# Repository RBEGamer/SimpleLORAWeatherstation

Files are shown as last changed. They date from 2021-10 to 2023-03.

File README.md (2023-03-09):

# SimpleLORAWeatherstation

Simple temperature and rel. humidity Lora-Wan sensor based on the DHT22 and RFM95/RFM96 in interaction with an Arduino Nano.

The special feature of this version is the use of the Lora radio standard in combination with the Lora-Wan protocol. 
This allows the reception of sensor data over many kilometers.
To enable the transmission of the sensor data to the Internet, a decentralized network of receiving stations (gateways) is used.
These are usually provided by private individuals or companies.

Another advantage of this architecture is that not everyone needs a gateway who wants to send data with his Lora-Wan device.
Of course, only as long as a gateway is in range. For this purpose, there are ready-made maps that show the coverage at a location.

These gateways can send their data to a server on the Internet, which then provides them as e.g. REST api.
In this case we use the TTN provider [The Things Network (TTN)](https://www.thethingsnetwork.org).

## EXAMPLE SENSOR

### FINAL SENSOR

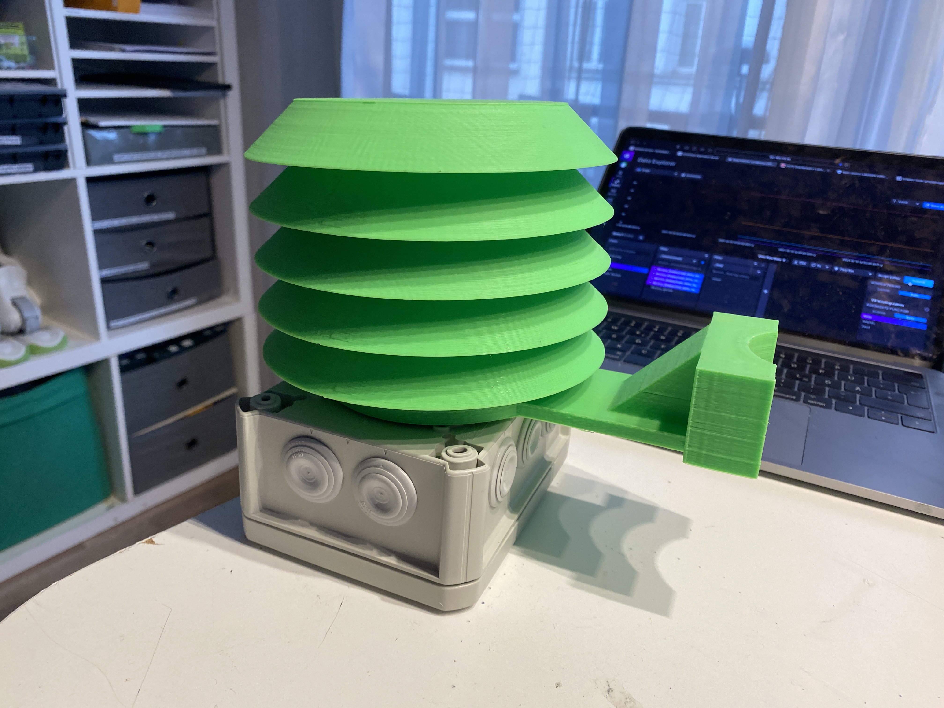
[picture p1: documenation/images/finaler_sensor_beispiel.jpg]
FINALER_SENSOR


### WITH MOUNTED SOLAR PANEL

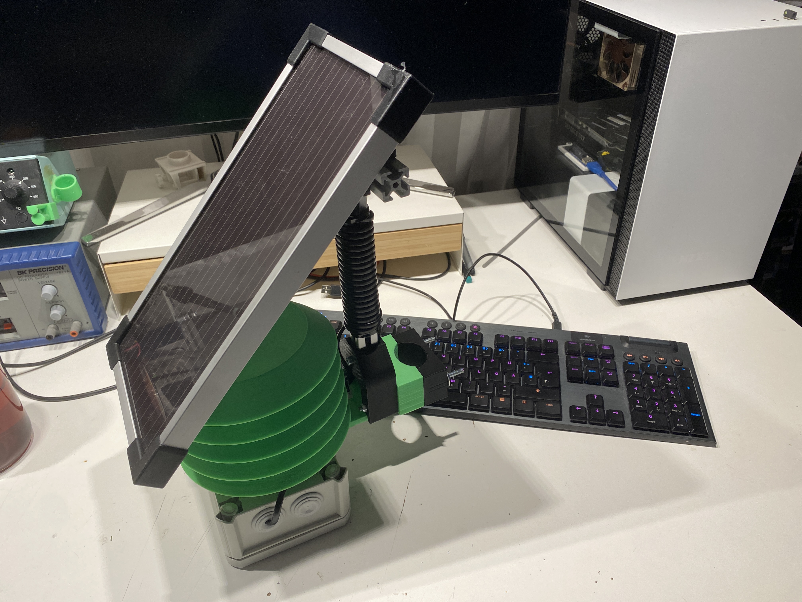
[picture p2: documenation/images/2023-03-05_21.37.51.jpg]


### PROTOTYPE

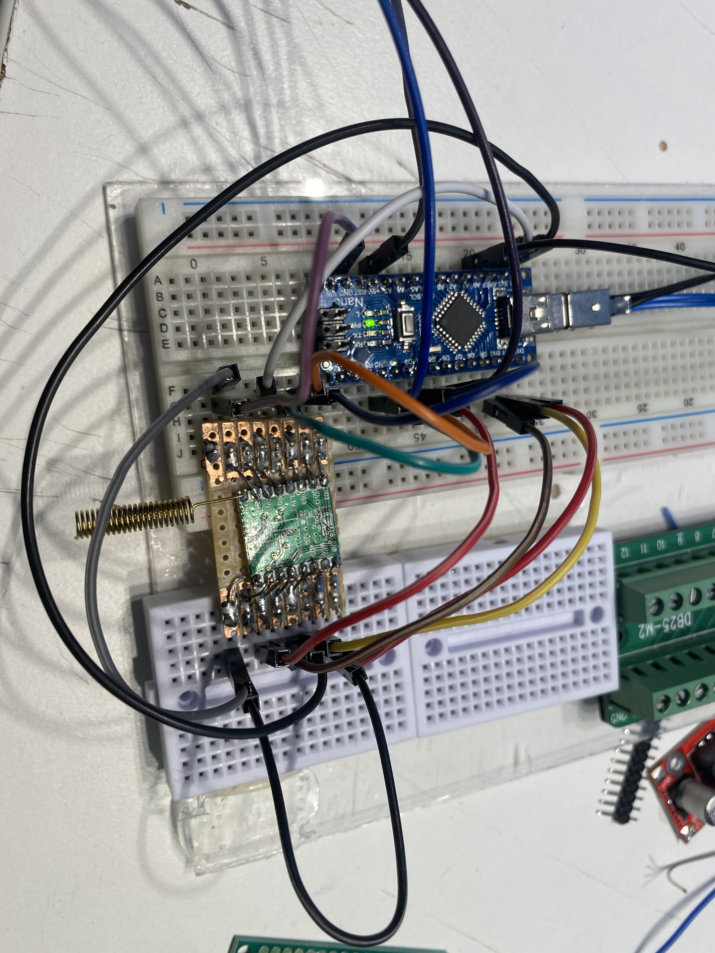
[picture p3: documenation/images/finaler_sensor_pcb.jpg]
PCB


## SETUP

### HARDWARE SETUP

#### COMPONENTS

* Arduino Nano
* DHT22
* RFM95, RFM95W, RFM96
* Steckbrett
* Jumperwires

* 3D printed parts - `src/src_stl`
* IP54 case 150x110x70mm

* `Adafruit Universal USB DC Solar Lithium Ion Polymer Lipo Charger` - Solar Support
* `10W Solarpanel 12V ` - Solar Support
* `iPo Akku Lithium-Ion Polymer Batterie 3,7V 2000mAh` - Solar Support

#### TOOLS

* soldering iron

#### SCHEMATIC

The construction of the circuit is relatively simple. However, the `RFM95` module cannot be plugged directly onto the breadboard, because this uses a different grid size of 2.0mm and the breadboard 2.54mm. So solder jumperwires directly or use a custom PCB - `src/src_rfmbreadboardadapter`.

The Arduino Nano and the RFM95 module communicate with each other via the SPI bus. In addition, the RFM95 module uses four other GPIO pins of the Arduino to exchange further status information with them. This includes a `RESET` signal and a receive event signal.

The SPI bus consists of the following signals in this configuration:

* `SCK` - Clock
* `MOSI` - Master Out Slave In 
* `MISO` - Master In Slave Out
* `CS` - Chip Select
* 
This way the RFM95 module is connected to the Arduino Nano as follows:

| Arduino Nano  	| RFM95 	|
|---	|---	|
| GND 	| GND 	|
| 3V3 	| 3.3V / VCC 	|
| D13 	| SCK 	|
| D12 	| MISO 	|
| D11 	| MOSI 	|
| D10 	| NSS 	|
| D5 	| RST 	|
| D2 	| DIO0 	|
| D3 	| DIO1 	|
| D4 	| DIO4 	|

After the RFM module has been connected, the DHT22 sensor can be connected.
However, this is only an example and other sensors can be used later.
It uses a bus protocol for communication which sends the sensor data to the Arduino via a GPIO.
So only one pin is used at the Arduino.
The bus is operated in a pull-up configuration, so an additional 10k resistor must be connected against 3.3V and the data pin.
Thus the 10K resistor is installed between DHT pin 1 and DHT pin 2.

| Arduino Nano 	| DHT22 	|
|---	|---	|
| GND 	| Pin 4 (GND)  	|
| 3V3 	| Pin 1 (VCC)  	|
| D6 	| Pin 2 (Data) 	|

The following graphic shows an exemplary circuit design.

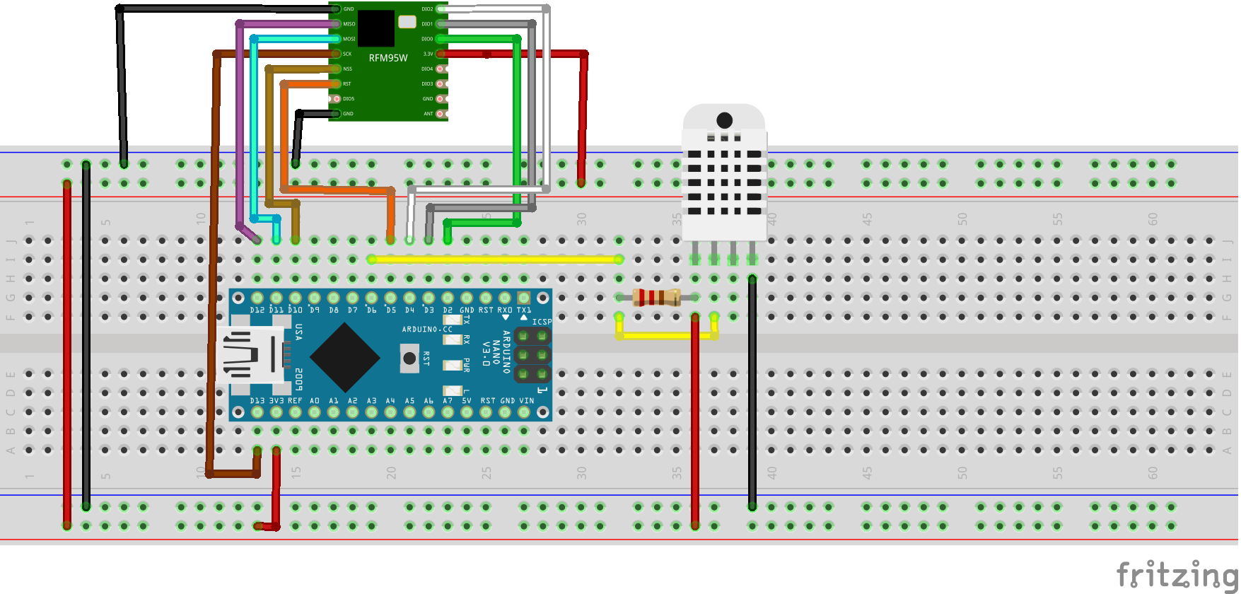
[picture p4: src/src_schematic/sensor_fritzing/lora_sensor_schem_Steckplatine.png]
STECKBRETT_SCHALTUNG


### The Things Network

In order to be able to program our sensor later on, it must first be christened. Each Lora-Wan device gets a fixed ID from the network to be used. In this case it is the TTN and there the sensor has to be registered. After this we get two keys, which are needed for an encrypted connection between. These are then inserted into the later Arduino program.

### Application registration

After registering an account, the TTN offers two options in the TTN Console:

* Application
* Gateway

The TTN groups multiple Lora devices into Applications, so a new Application with any name must be created first.

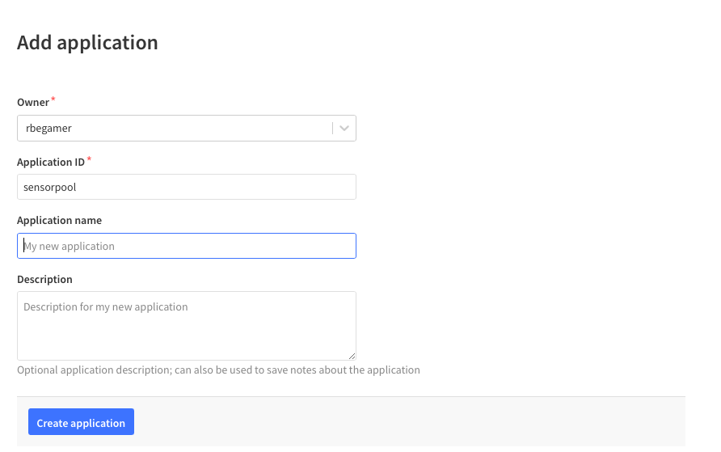
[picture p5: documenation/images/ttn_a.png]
Register Application


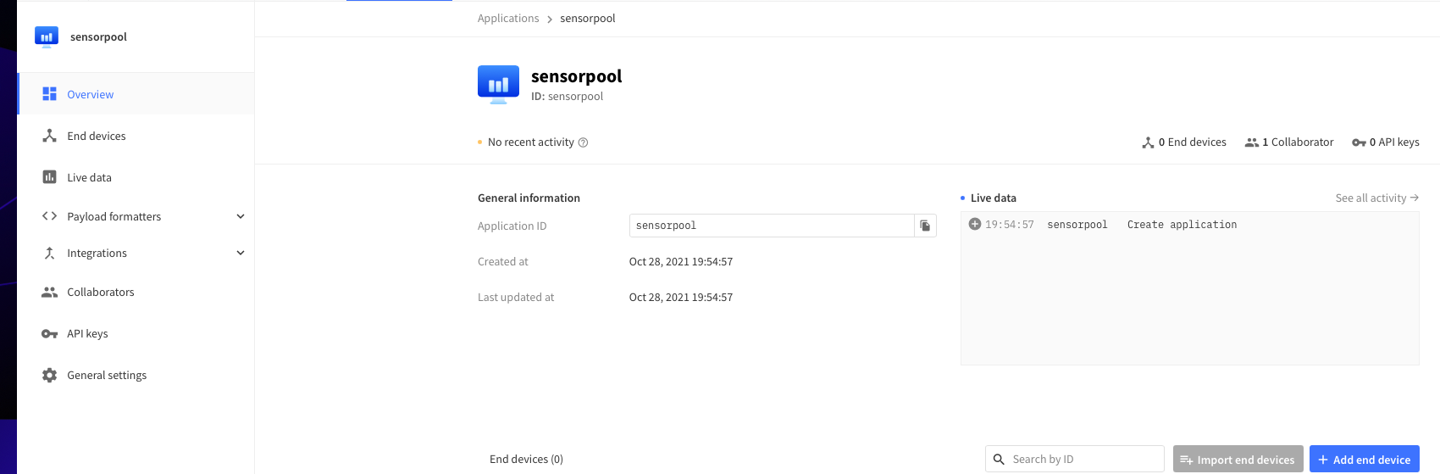
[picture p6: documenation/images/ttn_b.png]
Application


After creation, a Lora Wan device can be added via the **+ Add Enddevice** button.
Some information must be specified here. Since this is a self-built sensor, there is no ready template for it that can be used.

Here you must switch to the "Manually" tab and enter the following data:

| Key 	| Value 	|
|---	|---	 |
| Frequency plan	 | Europe 863-870MHz SF9 for RX2 - recommended |
| LoRaWAN Version 	 | MAC V1.0.3 |
| Activation mode 	 | Activation by personalisation (ABP) |

Then click on the three "Generate" buttons and finally "Register Device".
This completes the registration of the sensor.

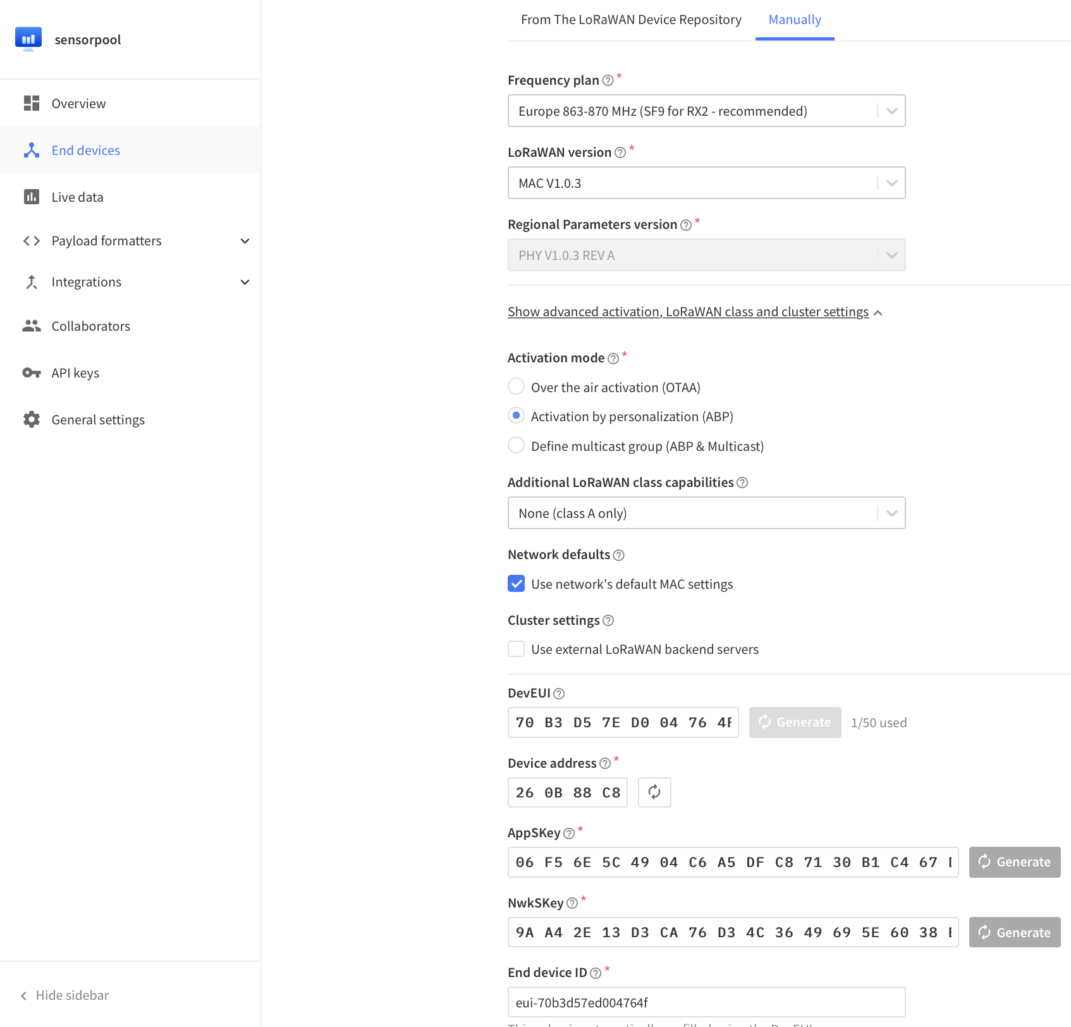
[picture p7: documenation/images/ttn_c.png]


On the overview, there is now some information. Here, three details about the parameterization are important.
These can be displayed in different formats. Click on the eye to display the key and the "<>" button to change the display.
The required information is listed in the following table.

| Information | Darstellung | Beispiel |
|---	|--- |--- |
| Device Adress	 | HEX, MSB ohne 0x | 260BA509 |
| NwkSKey | HEX, MSB | 0xE4, 0x14, 0xC5, 0x65 |
| AppSKeys | HEX, MSB | 0x0D, 0x79, 0xB8, 0x87.  |

The last step is only important here during development.
The network and the sensor remember how many packets they have already exchanged.
If the sensor is reprogrammed, this counter is not stored in the EEProm, they differ and the network no longer accepts packets from the sensor. Therefore this check is switched off for test purposes.

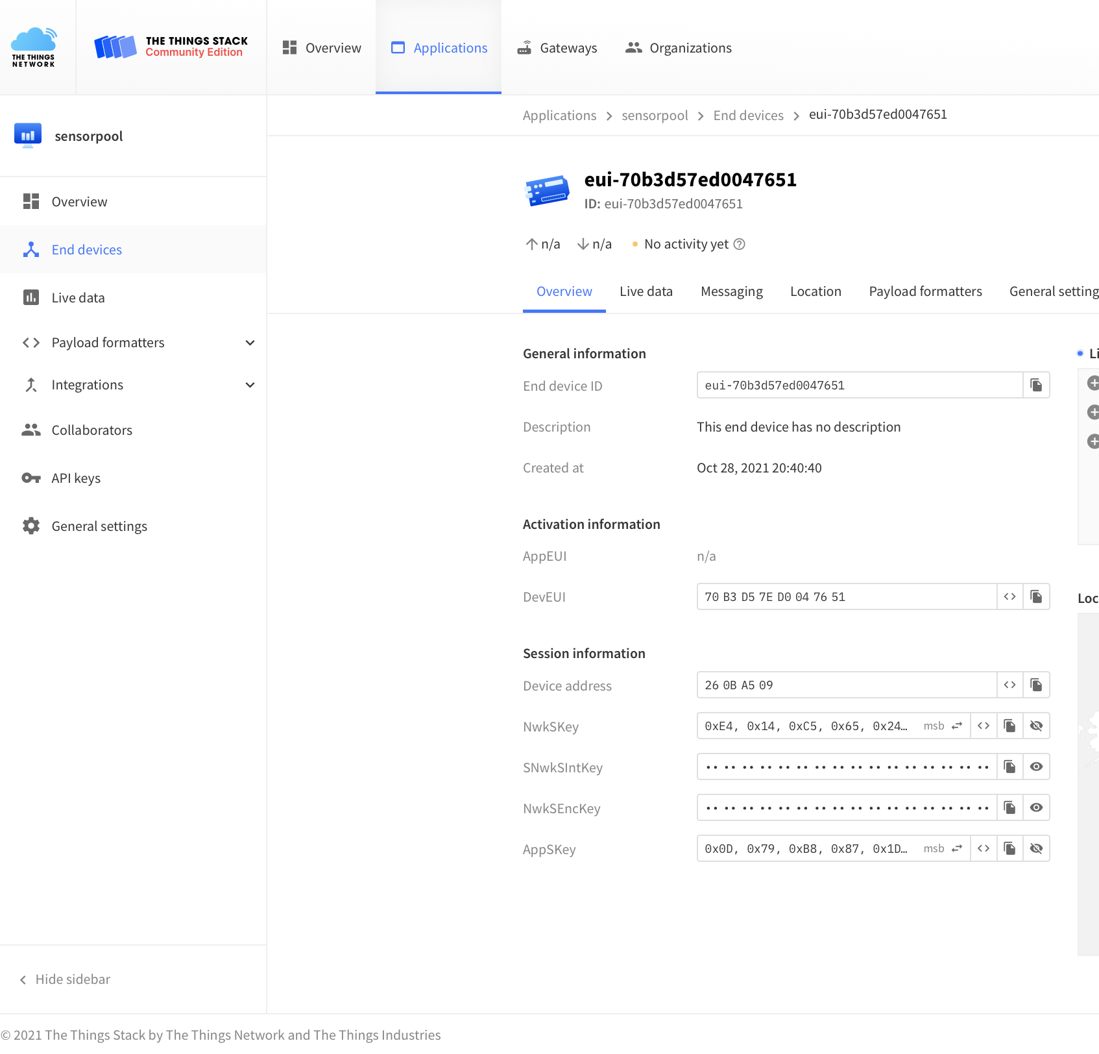
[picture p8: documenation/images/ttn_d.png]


Dazu auf der Sensor-Seite unter `General Settings -> Network Layer -> Advanced MAC settings -> Resets FRame Counter` auf `Enabled` setzten.

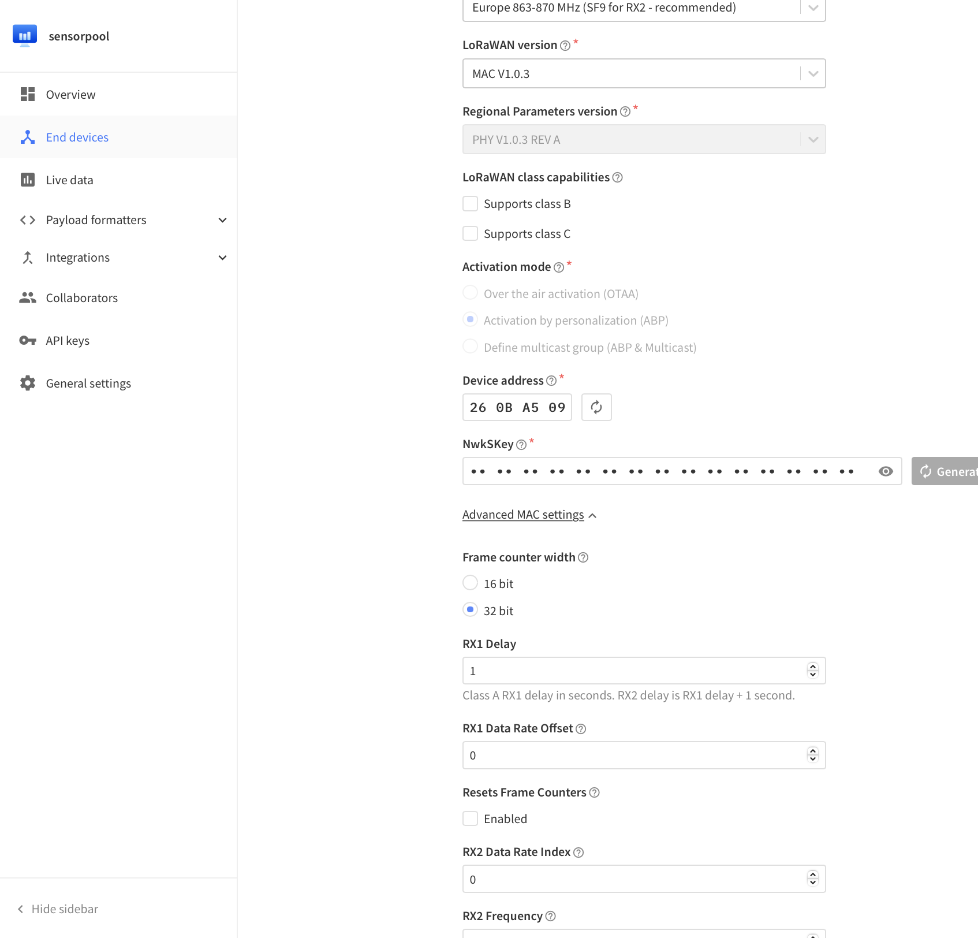
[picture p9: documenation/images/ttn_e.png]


### SOFTWARE SETUP ARDUINO

The Arduino Nano is programmed with the Aruino IDE. For the components used, however, ready-made libraries must be installed, which enable the simple control of the RFM95 module, as well as the DHT22.

Also the LoraWan protocol which is used here already exists in a corresponding library.

This can be done by the Arduino-Library Manager or by copying the corresponding folders from the `src_arduino/required_libraries` directory into the `Documents/Arduino/library` folder of the PC.

The following libraries must thus be installed:

| Arduino Libaray Name.  	|
|-------------------------	|
| Adafruit_Unified_Sensor 	|
| DHT_sensor_library      	|
| IBM_LMIC_framework      	|

All other software components are already included in the Arduino IDE installation, e.g. for the SPI communication.

After installing the libraries, the source code for the sensor can be opened.

This is located in the folder `src_arduino/lora_dht22_apb/lora_dht22_apb.ino`.
Here the necessary settings for the above pinouts have already been set.

Finally, the sensor must be parameterized and coupled with the one created in the TTN network.
For this purpose three different keys were created during the registration of the sensor in the TTN.

These must now be entered in the program as follows:

```c++
41 | //-------------------- LORA CONFIG ----------------------- //
42 | // NwkSKey MSB
43 | static const PROGMEM u1_t NWKSKEY[16] = {0xE4, 0x14, 0xC5, 0x65, 0x24, 0x2D, 0x7B, 0x60, 0x61, 0x43, 0xD3, 0xC1, 0x49, 0x87, 0x90, 0x45 };
44 | // AppSKey MSB
45 | static const u1_t PROGMEM APPSKEY[16] = {0x0D, 0x79, 0xB8, 0x87, 0x1D, 0xD4, 0x64, 0xFA, 0xCC, 0x5B, 0x3B, 0xE0, 0x08, 0x0E, 0x7A, 0x22 };
46 | // LoRaWAN address = '0x' + Device Address 
47 | static const u4_t DEVADDR = 0x260BA509; //UNIQUE LORA DEVICE ID
```

Afterwards the program can be compiled and uploaded.
To do this, the appropriate Arduino board must be selected beforehand.

This can be set in the menu under Tools:

| Arduino Nano Board-Settings 	| Wert |
|---	|---	 |
| Board 	| Arduino Nano |
| Prozessor 	| ATmega380p (Old Bootloader) | 
| Port 	| COMxx (WIN), /dev/ttyXX (Linux, Mac)  |

### ChirpStack

#### Device-Profile

Create a new Device Profile and use this for each sensor of this type later on.

##### GENERAL

* `Device-profile name` => `abp_dht22_sensor_node_profile`
* `LoRaWAN MAC version` => `1.0.3` 
* `LoRaWAN Regional Parameters revision *` => `A`
* `ADR algorithm` => `Default ADR algorithm`
* `Max EIRP *` => `0` 
* `Uplink interval (seconds)` => `5` 

##### CODEC: Javascript Decode Function

```js
//UNCOMMENT FOR TTN DOWNLINK DECODER
//function decodeDownlink(input) {
//const bytes = input.bytes
//const TTN_COMPABILITY = true;

// UNCOMMENT FOR CHIRPSTACK CODEC
// function Decode(fPort, bytes) { 
//const TTN_COMPABILITY = false;

    var result = "";
    var resobj = {
        warnings: [],
        errors: [],
        data: {

        }
    };

    var entryobj = {};

    for (var i = 0; i < bytes.length; i++) {
        result += (String.fromCharCode(bytes[i]));
    }
    //SPLIT COMPLETE STRING BY ; TO GET INDIVIDUAL ENTRIES
    const sp = String(result).split(';');
    if(sp){
        //FOR EACH ENTRY
        for(var i = 0; i < sp.length;i++){
            if(sp[i].includes('=')){
                //SPLIT ENTRY FOR =
                const spe = String(sp[i]).split('=');
                if(spe.length === 3){
                    //PARSE EACH ENTRY <type>=<key>=<value>
                    //s => STRING
                    //f => float
                    //i => int
                    if(spe[0] === "s"){
                        entryobj[String(spe[1])] =spe[2];
                    }else if(spe[0] === "f"){
                        entryobj[String(spe[1])] = parseFloat(spe[2]);
                        //CHECK FOR Nan not a number and set to null
                        if(isNaN(entryobj[String(spe[1])])){
                            entryobj[String(spe[1])] = null;
                        }
                    }else if(spe[0] === "i"){
                        entryobj[String(spe[1])] = parseInt(spe[2], 10);
                        //CHECK FOR Nan not a number and set to null
                        if(isNaN(entryobj[String(spe[1])])){
                            entryobj[String(spe[1])] = null;
                        }
                    }
                }
            }
        }
    }
    if(TTN_COMPABILITY){
        resobj["data"] = entryobj;
        return resobj;
    }else{
        return entryobj;
    }

}
```

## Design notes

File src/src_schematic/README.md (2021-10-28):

# SCHALTPLAN

## SCHALTPLAN DES LORA SENSORS

Hier wurde die Fritzing Software verwendet um einen vereinfachten Schaltplan des Sensors zu erstellen.
Hier kann einfach die `lora_sensor_schem.fzz` Datei geöffnet werden.

Zusätzlich müssen die folgenden Dateien Importiert werden, dies kann einfach durch das öffnen der Datei in Fritzing geschehen:

* [RFM95W_LoRa_Module_v1-2.fzpz](https://forum.fritzing.org/t/hoperf-rfm95w-lora-module/10011)
* [HT22 Humidity and Temperature Sensor.fzpz](https://github.com/adafruit/Fritzing-Library)

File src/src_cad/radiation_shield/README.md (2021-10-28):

# 3D Druck

Für den Sensor werden folgende 3D gedruckten Teile/Dateien benötigt:

* 1x `SHT15_mount_V1.stl` (Sensorhalterung, optional)
* 1x `Rad_Shd_Vert_mount_V1.stl` (Halterung)
* 1x `Rad_Shd_Vert_mount_V1.stl` (Deckel)
* 1-3x `Rad_Shd_Fin_V1.stl` (Zwischenstücke, je nach gewünschter Höhe)
* 1x `Rad_Shd_Base_V1.stl` (Basisplatte)

## Einstellungen

Für alle benötigten Teile sind keine besondereren Einstellungen notwendig.
Als Support-Typ ist jedoch `Raft` von Vorteil damit sich der Druck nicht von der Grundplatte lösst.

## Nachbehandlung

Fuer einen wirklichen Einsatz im Freien, ist eine Lakierung mit UV-Klarlack von Vorteil.
So wird gewährleistet, dass die Farbe und das Material unter Sonne und Regen beständig bleibt.

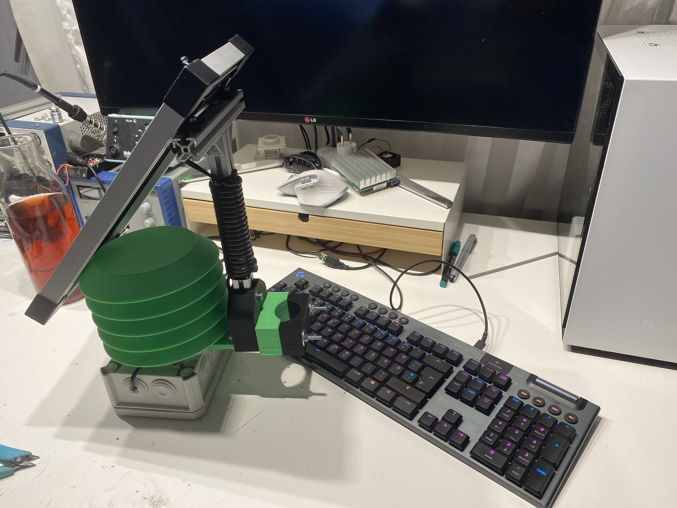
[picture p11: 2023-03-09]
documenation/images/2023-03-05_21.37.55.jpg

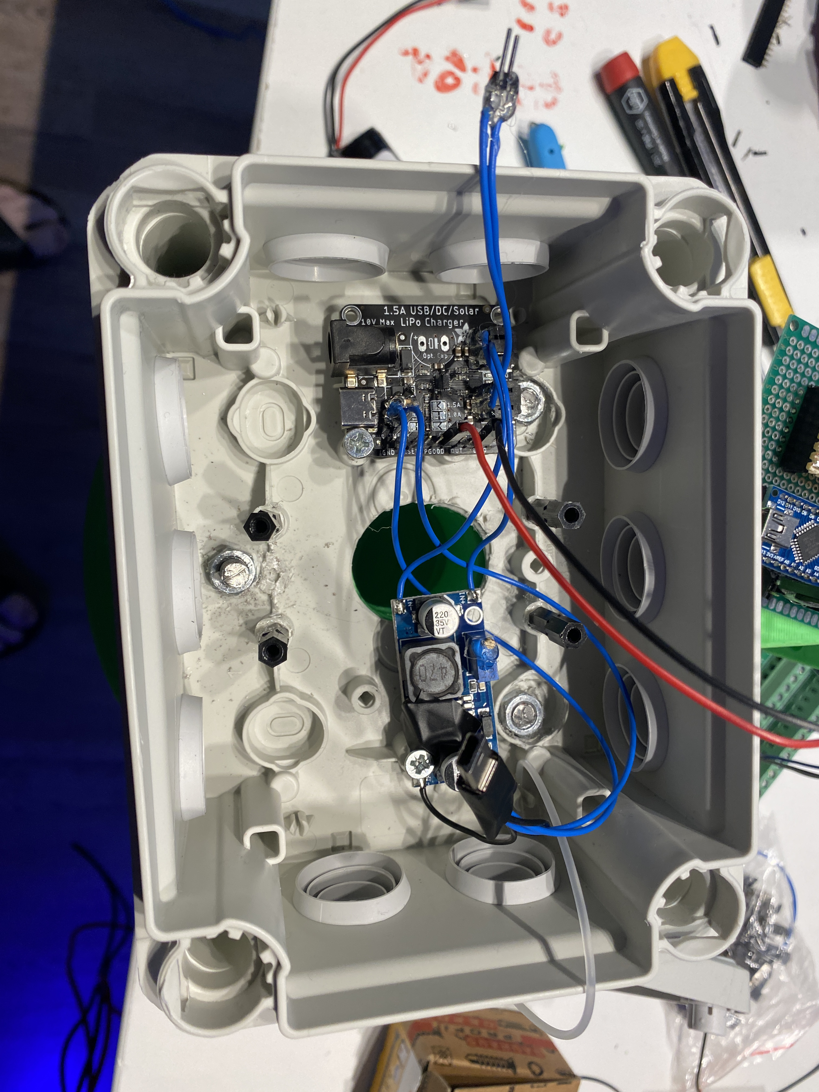
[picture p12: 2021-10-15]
documenation/images/2021-10-15 12.23.51.jpg

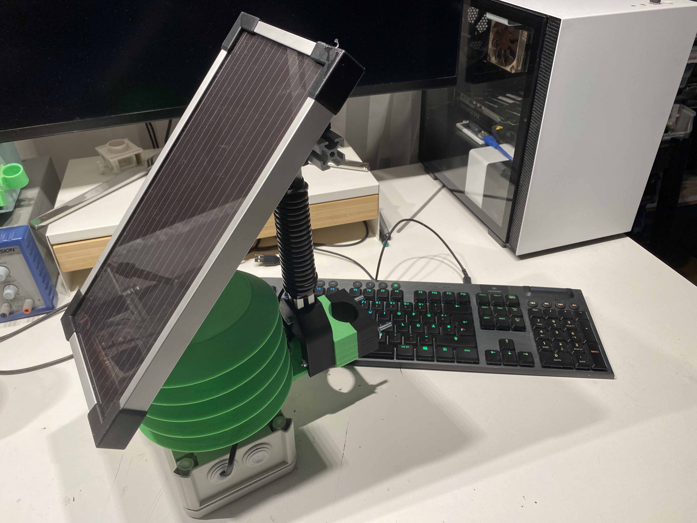
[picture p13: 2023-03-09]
documenation/images/2023-03-05_21.37.42.jpg

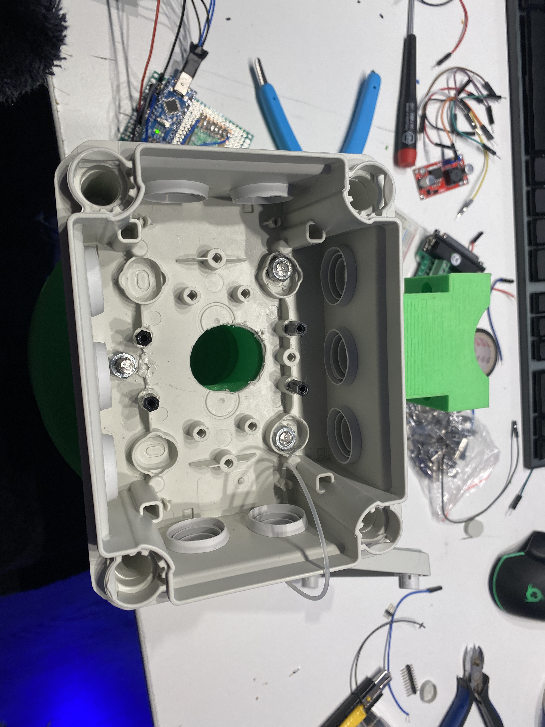
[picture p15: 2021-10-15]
documenation/images/2021-10-15 12.13.19.jpg

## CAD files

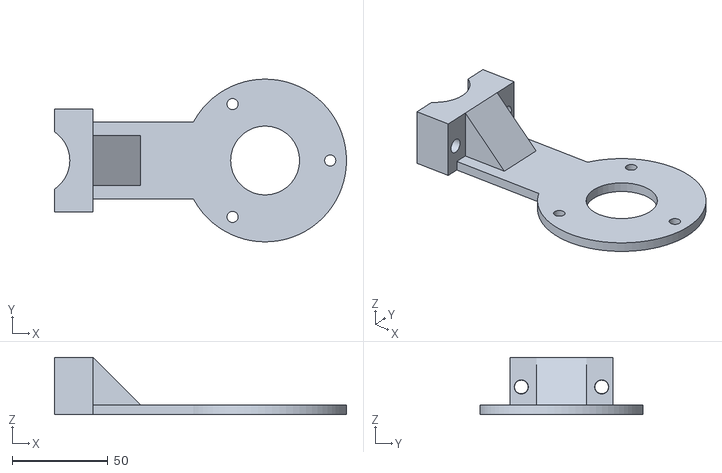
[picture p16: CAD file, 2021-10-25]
src/src_cad/radiation_shield/Rad_Shd_Vert_mount_V1.stl
152.5 x 85.0 x 30.0

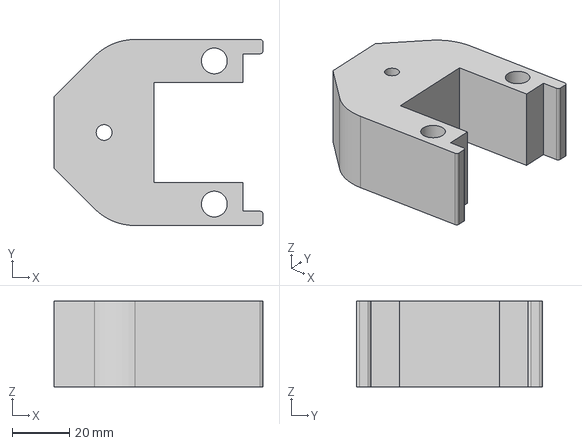
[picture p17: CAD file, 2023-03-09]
src/src_cad/solar_panel_item_mount.step
73.0 x 65.0 x 30.0 mm

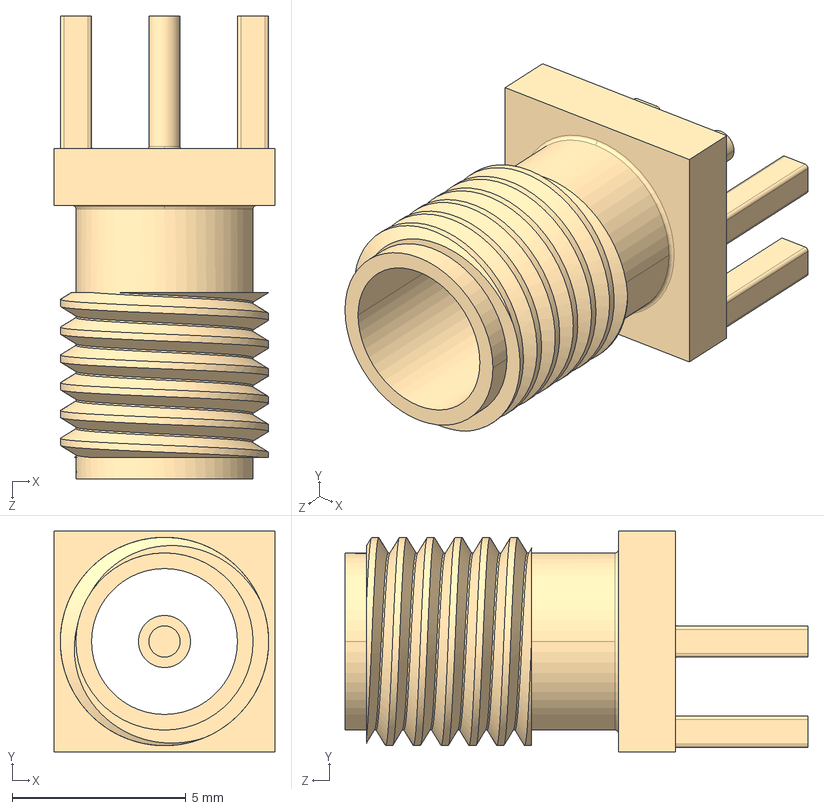
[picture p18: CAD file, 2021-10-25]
src/src_rfmbreadboardadapter/rfm9x_breakout_board-master/KiCAD/rev.1/lib_3D/Connector_Coaxial_SMA_edge_clear.step
6.35 x 6.35 x 13.3 mm

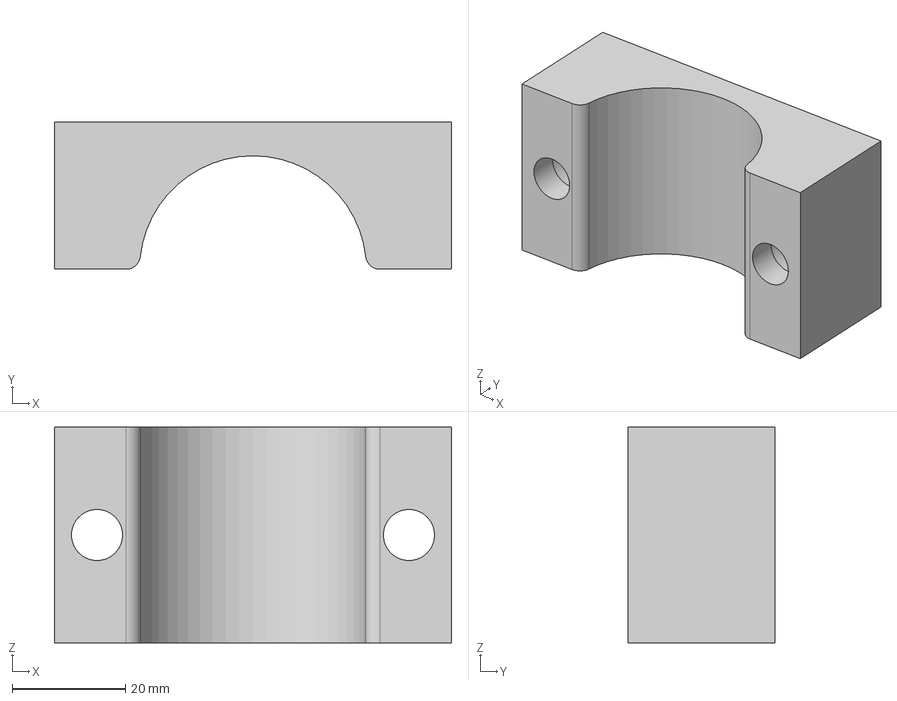
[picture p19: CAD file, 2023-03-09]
src/src_cad/back_mount.step
70.0 x 26.0 x 38.0 mm

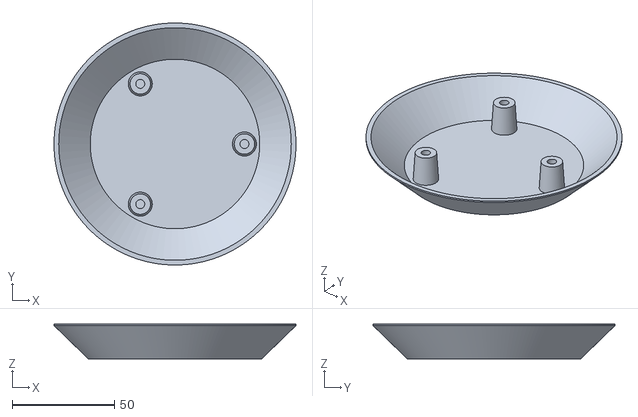
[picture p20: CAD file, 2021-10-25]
src/src_cad/radiation_shield/Rad_Shd_Top_V1.stl
118.5 x 118.5 x 17.0

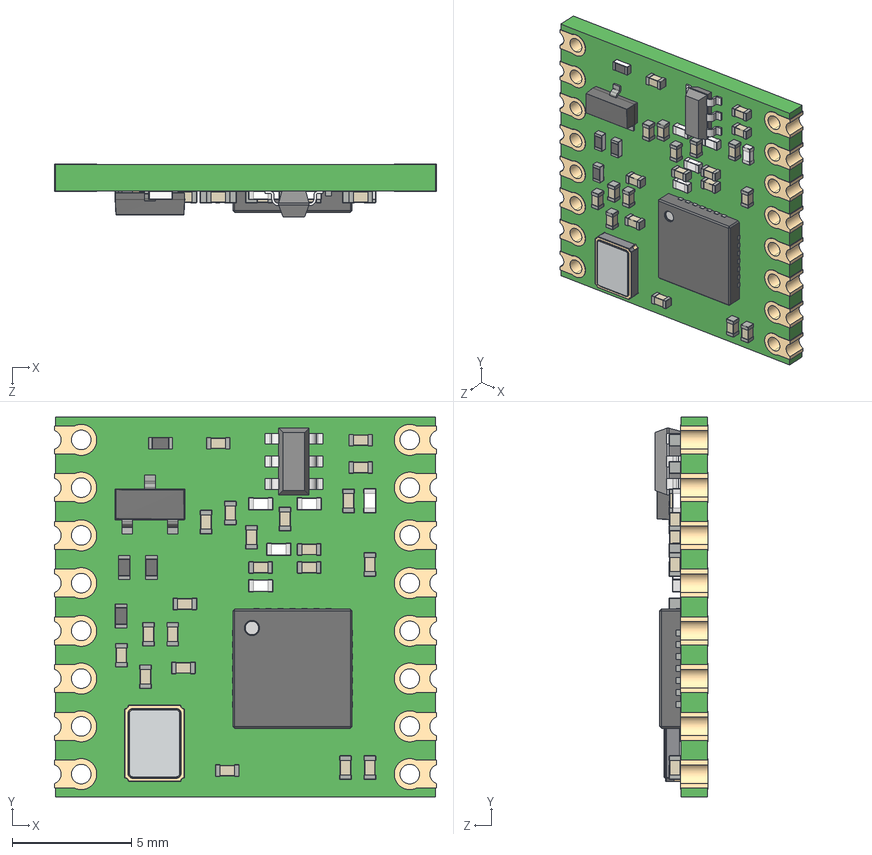
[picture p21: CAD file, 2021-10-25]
src/src_rfmbreadboardadapter/rfm9x_breakout_board-master/KiCAD/rev.1/lib_3D/RFM9xW.step
16.0 x 15.9 x 2.23 mm
Board
Cap0402 x 21
SW3dPS-inductor_0402_white x 5
SW3dPS-SOT-23-6
QFN28
TXC_7M
Res0402 x 4
User_Library-3-lead_sot23-3
Goldcontact x 16

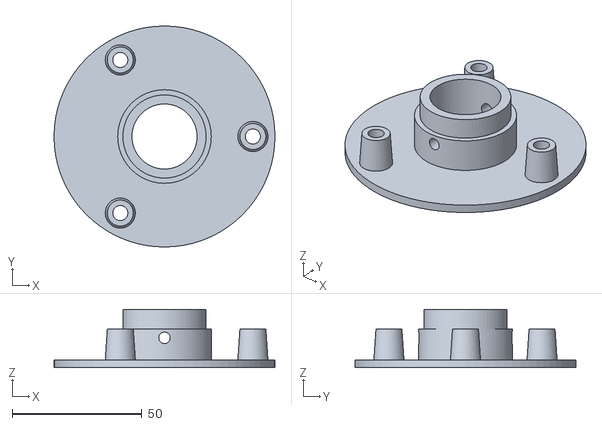
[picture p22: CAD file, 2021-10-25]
src/src_cad/radiation_shield/Rad_Shd_Base_V1.stl
85.0 x 85.0 x 22.5

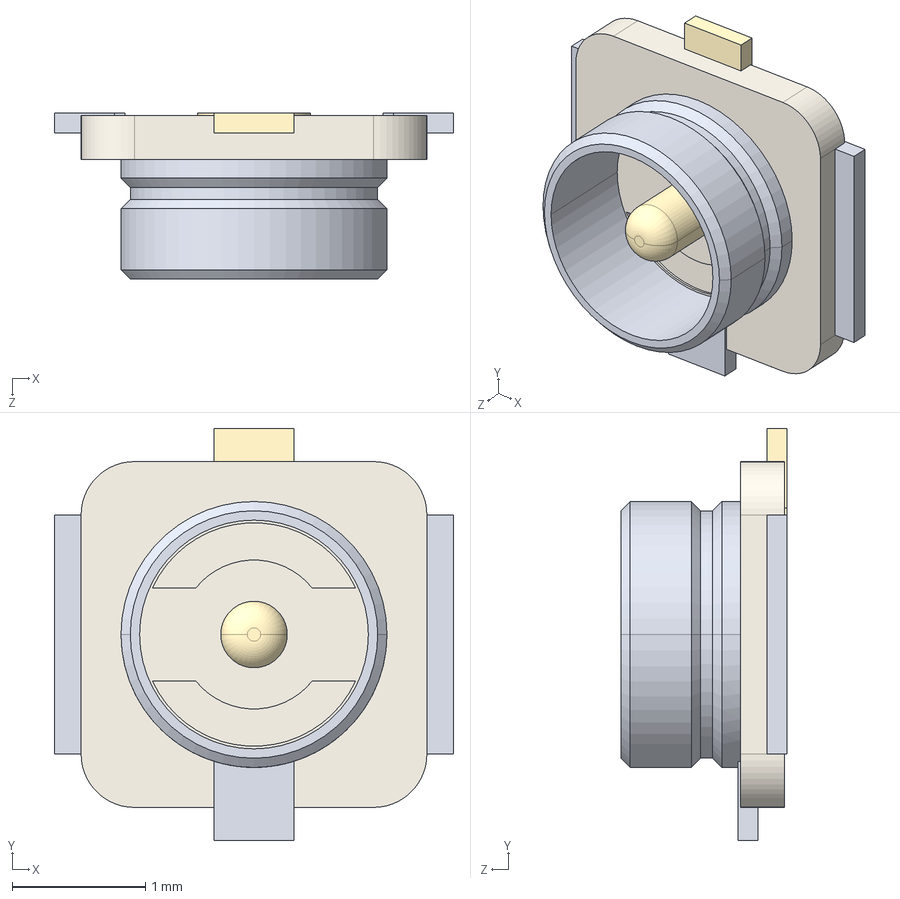
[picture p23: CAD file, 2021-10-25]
src/src_rfmbreadboardadapter/rfm9x_breakout_board-master/KiCAD/rev.1b/lib_3D/Connector Coaxial U.FL_Hirose_U.FL-R-SMT-1_Vertical.step
3.00 x 3.10 x 1.25 mm

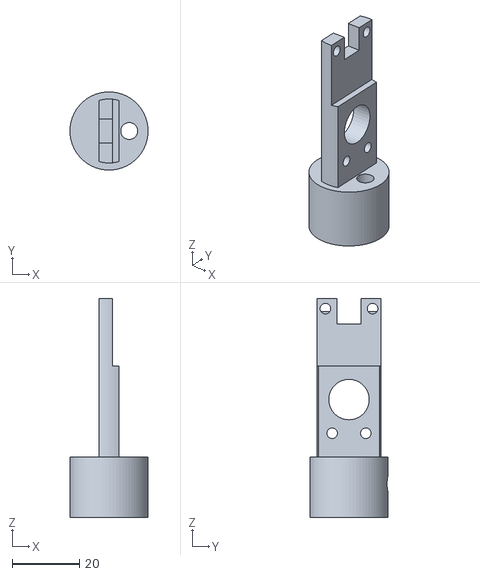
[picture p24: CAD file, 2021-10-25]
src/src_cad/radiation_shield/SHT15_mount_V1.stl
23.2 x 23.2 x 65.0

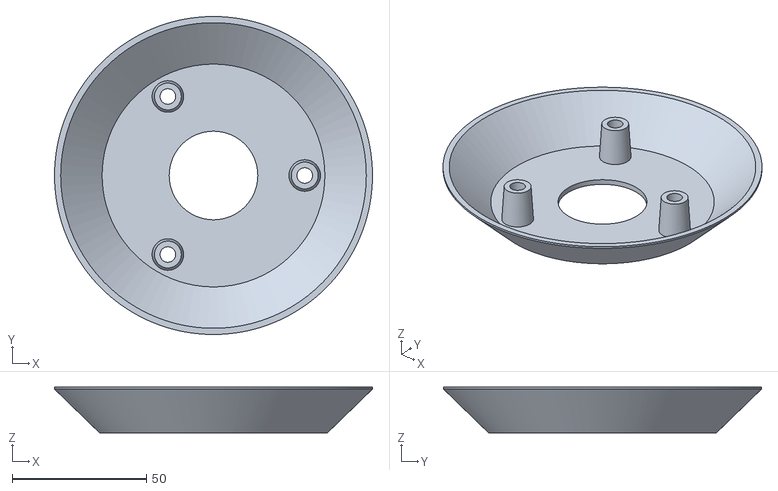
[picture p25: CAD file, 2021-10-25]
src/src_cad/radiation_shield/Rad_Shd_Fin_V1.stl
118.5 x 118.5 x 17.0

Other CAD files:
src/src_cad/back_mount.stl
src/src_cad/solar_panel_item_mount.stl
src/src_cad/weatherstation_mounts.f3d

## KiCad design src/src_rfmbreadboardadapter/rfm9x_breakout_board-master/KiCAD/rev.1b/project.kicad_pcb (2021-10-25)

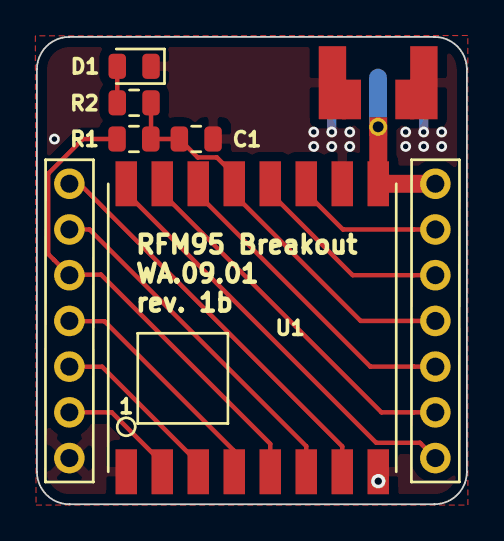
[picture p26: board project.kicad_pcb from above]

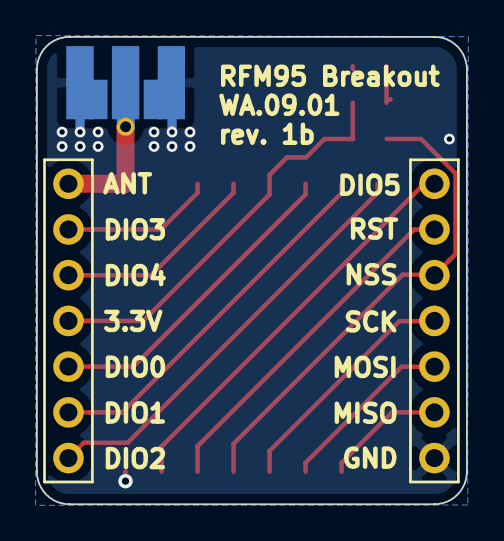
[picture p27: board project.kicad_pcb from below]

Board: 2 copper layers, 23.9 x 26.0 mm, 8 parts (3 on the bottom side), 15 nets.

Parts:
C1: 10uF; C_0805_2012Metric
D1: LED; LED_0805_2012Metric
J1, J2: Conn_01x07; PinHeader_1x07_P2.54mm_Vertical_2
J3: Conn_Coaxial; Connector_Coaxial_SMA_edge_combined
R1: 10k; R_0805_2012Metric
R2: 330; R_0805_2012Metric
U1: RFM95W

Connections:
+3V3: C1.2, J2.4, R1.1, R2.2, U1.13
/ANT: J2.7, J3.1, U1.9
/DIO0: J2.3, U1.14
/DIO1: J2.2, U1.15
/DIO2: J2.1, U1.16
/DIO3: J2.6, U1.11
/DIO4: J2.5, U1.12
/DIO5: J1.7, U1.7
/MISO: J1.2, U1.2
/MOSI: J1.3, U1.3
/NSS: J1.5, R1.2, U1.5
/RST: J1.6, U1.6
/SCK: J1.4, U1.4
GND: C1.1, D1.1, J1.1, J3.2, U1.1, U1.8, U1.10
unnamed: D1.2, R2.1

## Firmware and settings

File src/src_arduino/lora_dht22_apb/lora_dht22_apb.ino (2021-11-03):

/*
 * FH Aachen Makerspace
 * The FH Aachen makerspace lora based dht22 solar powered sensor node 
 * Initial Version: Marcel Ochsendorf 15.10.2021 https://github.com/RBEGamer/MSFHAC_Lora_DHT22_Node/
 * 
 * 
 * COMPONENTS:
 * Arduio Nano
 * DHT22
 * RFM95(W)
 * Step-Up
 * 3.7.V 1S Lipo Cell
 * Solar Charing Board
 * 
 * 
 */



#define SENSOR_TYPE_DHT22
#define SENSOR_TYPE_IKEA_VINDRIKTNING



#include <lmic.h>
#include <hal/hal.h>
#include <SPI.h>
#include "DHT.h"

//--------------------- USER CONFIG ------------------------ //


#define BATT_ADC_PIN A0 //BATTERY VOLTAGE ADC PIN
#define BATT_ADC_MAX_RANGE 5.0 //ADC VALUE * (BATT_ADC_MAX_RANGE*1023) => ON 3.3V MCU SET THIS TO 3.3V
#define CHARHING_OK_INPUT 7 //PIN FOR GETTING CHARGING STATE FROM SOLAR CHARGER LOW IF CHARGING IS ACTIVE




#ifdef SENSOR_TYPE_DHT22
#define DHTPIN 6 //DHT SENSOR PIN   
#define DHTTYPE DHT22
DHT dht(DHTPIN, DHTTYPE); //Der Sensor wird ab jetzt mit „dth“ angesprochen
#endif

#ifdef SENSOR_TYPE_IKEA_VINDRIKTNING
#include "IkeaVindriktningSerialCom.h" 
#include "IkeaVindriktningTypes.h"
particleSensorState_t state;
#endif



static uint8_t payload[256] = { 0 }; //INCREASE FOR LARGER PAYLOADS 


#define RFM95_RST_PIN 5 //RESET
#define RFM95_NSS_PIN 10 //NSS / CS
#define RFM95_DIO0_PIN 2 //DIO0
#define RFM95_DIO1_PIN 3 //DIO1
#define RFM95_DIO2_PIN 4 //DIO2

//-------------------- LORA CONFIG ----------------------- //

//#ifdef SENSOR_TYPE_DHT22
//static const PROGMEM u1_t NWKSKEY[16] = {0xCC, 0x46, 0x1B, 0x83, 0xF1, 0x79, 0xAB, 0x6D, 0x73, 0x0E, 0x7D, 0xC4, 0x9F, 0x54, 0x18, 0xDA };
//static const u1_t PROGMEM APPSKEY[16] = { 0x4B, 0x51, 0x95, 0xA5, 0x45, 0x1F, 0xA9, 0x76, 0xD9, 0x50, 0xB4, 0xDA, 0x29, 0xAF, 0x01, 0x6E };
//static const u4_t DEVADDR = 0x260B1A42;
//#endif

#ifdef SENSOR_TYPE_IKEA_VINDRIKTNING
static const PROGMEM u1_t NWKSKEY[16] = {0x66, 0x1F, 0x14, 0x94, 0xC2, 0xA7, 0x7C, 0x0F, 0xE6, 0x50, 0x75, 0xDA, 0xDA, 0x73, 0x33, 0x00 };
static const u1_t PROGMEM APPSKEY[16] = { 0xB8, 0xC7, 0x43, 0x72, 0x2A, 0xD5, 0x60, 0x41, 0x1D, 0x6E, 0xEA, 0x57, 0xEA, 0x33, 0x14, 0xFB };
static const u4_t DEVADDR = 0x260B478B;
#endif



//--------------------- END CONFIG ---------------------- //

void os_getArtEui (u1_t* buf) { }
void os_getDevEui (u1_t* buf) { }
void os_getDevKey (u1_t* buf) { }


static osjob_t sendjob;

const unsigned TX_INTERVAL = 60;

// Pin mapping
const lmic_pinmap lmic_pins = {
    .nss = RFM95_NSS_PIN,
    .rxtx = LMIC_UNUSED_PIN,
    .rst = RFM95_RST_PIN,
    .dio = {RFM95_DIO0_PIN, RFM95_DIO0_PIN, RFM95_DIO0_PIN}, //DIO0 DIO1 DIO2 CONNECT ALL OF THEM
};

void onEvent (ev_t ev) {
    Serial.print(os_getTime());
    Serial.print(": ");
    switch(ev) {
        case EV_SCAN_TIMEOUT:
            Serial.println(F("EV_SCAN_TIMEOUT"));
            //os_setTimedCallback(&sendjob, os_getTime()+sec2osticks(TX_INTERVAL), do_send);
            break;
        case EV_BEACON_FOUND:
            Serial.println(F("EV_BEACON_FOUND"));
            break;
        case EV_BEACON_MISSED:
            Serial.println(F("EV_BEACON_MISSED"));
            break;
        case EV_BEACON_TRACKED:
            Serial.println(F("EV_BEACON_TRACKED"));
            break;
        case EV_JOINING:
            Serial.println(F("EV_JOINING"));
            break;
        case EV_JOINED:
            Serial.println(F("EV_JOINED"));
            break;
        case EV_RFU1:
            Serial.println(F("EV_RFU1"));
            break;
        case EV_JOIN_FAILED:
            Serial.println(F("EV_JOIN_FAILED"));
            break;
        case EV_REJOIN_FAILED:
            Serial.println(F("EV_REJOIN_FAILED"));
            break;
        case EV_TXCOMPLETE:
            Serial.println(F("EV_TXCOMPLETE (includes waiting for RX windows)"));
            if (LMIC.txrxFlags & TXRX_ACK)
              Serial.println(F("Received ack"));
            if (LMIC.dataLen) {
              Serial.println(F("Received "));
              Serial.println(LMIC.dataLen);
              Serial.println(F(" bytes of payload"));
            }
            // Schedule next transmission
            os_setTimedCallback(&sendjob, os_getTime()+sec2osticks(TX_INTERVAL), do_send);
            break;
        case EV_LOST_TSYNC:
            Serial.println(F("EV_LOST_TSYNC"));
            //os_setTimedCallback(&sendjob, os_getTime()+sec2osticks(TX_INTERVAL), do_send);
            break;
        case EV_RESET:
            Serial.println(F("EV_RESET"));
            //os_setTimedCallback(&sendjob, os_getTime()+sec2osticks(TX_INTERVAL), do_send);
            break;
        case EV_RXCOMPLETE:
            // data received in ping slot
            Serial.println(F("EV_RXCOMPLETE"));
            break;
        case EV_LINK_DEAD:
            Serial.println(F("EV_LINK_DEAD"));
            break;
        case EV_LINK_ALIVE:
            Serial.println(F("EV_LINK_ALIVE"));
            //os_setTimedCallback(&sendjob, os_getTime()+sec2osticks(TX_INTERVAL), do_send);
            break;
         default:
            Serial.println(F("Unknown event"));
            //os_setTimedCallback(&sendjob, os_getTime()+sec2osticks(TX_INTERVAL), do_send);
            break;
    }
}


String payload_str = "";


#ifdef SENSOR_TYPE_DHT22
void prepare_payload_dht22(){
  payload_str += "f=TEMP=";
  float Luftfeuchtigkeit = dht.readHumidity(); //die Luftfeuchtigkeit auslesen und unter „Luftfeutchtigkeit“ speichern
  float Temperatur = dht.readTemperature();//die Temperatur auslesen und unter „Temperatur“ speichern

  // ADD TEMPERATURE
  if(isnan(Temperatur)){
    payload_str.concat("null");
  }else{
   payload_str.concat(Temperatur);
  }
  payload_str += ";f=HUM=";

  //ADD HUMIDITY
  if(isnan(Luftfeuchtigkeit)){
    payload_str.concat("null");
  }else{
   payload_str.concat(Luftfeuchtigkeit);
  }

  payload_str += ";";

  }
#endif

#ifdef SENSOR_TYPE_IKEA_VINDRIKTNING
void prepare_payload_vindriking(){
      payload_str += "f=PM25=";
      for(int i = 0; i < 1000; i++){
        IkeaVindriktningSerialCom::handleUart(state);
        delay(10);
      } 
    payload_str += String(state.lastPM25); 
    payload_str += ";";

  }
#endif




int create_payload_buffer(){
  payload_str = "";
  
  #ifdef SENSOR_TYPE_DHT22
  prepare_payload_dht22();
  #endif

  #ifdef SENSOR_TYPE_IKEA_VINDRIKTNING
  prepare_payload_vindriking();
  #endif

  payload_str += "f=BATT=";
  //ADD BATTERY AND CHARGING STATE
  float batt = analogRead(BATT_ADC_PIN);
  batt = batt * (BATT_ADC_MAX_RANGE/1023);
  payload_str.concat(batt);
  payload_str += ";i=CHG=";

  const bool ch_ok= !digitalRead(CHARHING_OK_INPUT);
  payload_str.concat(ch_ok);
  payload_str += ";";


  


    
   payload_str += "s=FW=42;";
   //CUT DOWN LENGTH
  int sz = payload_str.length();
  if(payload_str.length()> sizeof(payload)){
    sz = sizeof(payload);
  }

  for(int i = 0; i < sizeof(payload); i++){
    payload[i] = 0;  
  }
  
  //COPY INTO CHAR ARRAY
  payload_str.toCharArray(payload, sz);
  Serial.println(payload_str);
  Serial.println((char*)payload);

  
  return sz;
  
  }


void do_send(osjob_t* j){
    // Check if there is not a current TX/RX job running
    if (LMIC.opmode & OP_TXRXPEND) {
        Serial.println(F("OP_TXRXPEND, not sending"));
    } else {

        //CREATE PAYLOAD BUFFER
        int buffer_len = create_payload_buffer();

        if(buffer_len > sizeof(payload)){
          buffer_len = sizeof(payload);
        }
        
        
        LMIC_setTxData2(1, payload, buffer_len-1, 0);
        Serial.println(F("Packet queued"));
    }
    // Next TX is scheduled after TX_COMPLETE event.
}

void setup() {
    Serial.begin(9600);
    Serial.println(F("Starting"));

    pinMode(CHARHING_OK_INPUT, INPUT_PULLUP);
    
    #ifdef VCC_ENABLE
    // For Pinoccio Scout boards
    pinMode(VCC_ENABLE, OUTPUT);
    digitalWrite(VCC_ENABLE, HIGH);
    delay(1000);
    #endif

    // LMIC init
    os_init();
    // Reset the MAC state. Session and pending data transfers will be discarded.
    LMIC_reset();

    // Set static session parameters. Instead of dynamically establishing a session
    // by joining the network, precomputed session parameters are be provided.
    #ifdef PROGMEM
    // On AVR, these values are stored in flash and only copied to RAM
    // once. Copy them to a temporary buffer here, LMIC_setSession will
    // copy them into a buffer of its own again.
    uint8_t appskey[sizeof(APPSKEY)];
    uint8_t nwkskey[sizeof(NWKSKEY)];
    memcpy_P(appskey, APPSKEY, sizeof(APPSKEY));
    memcpy_P(nwkskey, NWKSKEY, sizeof(NWKSKEY));
    LMIC_setSession (0x1, DEVADDR, nwkskey, appskey);
    #else
    // If not running an AVR with PROGMEM, just use the arrays directly
    LMIC_setSession (0x1, DEVADDR, NWKSKEY, APPSKEY);
    #endif

    #if defined(CFG_eu868)
    LMIC_setupChannel(0, 868100000, DR_RANGE_MAP(DR_SF12, DR_SF7),  BAND_CENTI);      // g-band
    LMIC_setupChannel(1, 868300000, DR_RANGE_MAP(DR_SF12, DR_SF7B), BAND_CENTI);      // g-band
    LMIC_setupChannel(2, 868500000, DR_RANGE_MAP(DR_SF12, DR_SF7),  BAND_CENTI);      // g-band
    LMIC_setupChannel(3, 867100000, DR_RANGE_MAP(DR_SF12, DR_SF7),  BAND_CENTI);      // g-band
    LMIC_setupChannel(4, 867300000, DR_RANGE_MAP(DR_SF12, DR_SF7),  BAND_CENTI);      // g-band
    LMIC_setupChannel(5, 867500000, DR_RANGE_MAP(DR_SF12, DR_SF7),  BAND_CENTI);      // g-band
    LMIC_setupChannel(6, 867700000, DR_RANGE_MAP(DR_SF12, DR_SF7),  BAND_CENTI);      // g-band
    LMIC_setupChannel(7, 867900000, DR_RANGE_MAP(DR_SF12, DR_SF7),  BAND_CENTI);      // g-band
    LMIC_setupChannel(8, 868800000, DR_RANGE_MAP(DR_FSK,  DR_FSK),  BAND_MILLI);      // g2-band
   
    #elif defined(CFG_us915)
    LMIC_selectSubBand(1);
    #endif

    // Disable link check validation
    LMIC_setLinkCheckMode(0);

    // TTN uses SF9 for its RX2 window.
    LMIC.dn2Dr = DR_SF9;

    // Set data rate and transmit power for uplink (note: txpow seems to be ignored by the library)
    LMIC_setDrTxpow(DR_SF7,14);




    #ifdef SENSOR_TYPE_DHT22
    //SETUP DHT22 
    dht.begin(); //DHT11 Sensor starten
    #endif

    #ifdef SENSOR_TYPE_IKEA_VINDRIKTNING
     IkeaVindriktningSerialCom::setup();
    
      for(int i = 0; i < 10000; i++){
        IkeaVindriktningSerialCom::handleUart(state);
        delay(1);
      }
     
     
    #endif


    
    // Start job
    do_send(&sendjob);
}


unsigned long prev = 0;
unsigned long curr = 0;
const int interval = 1000*60;


void loop() {
    os_runloop_once();

    curr = millis();
    if(curr - prev >= interval){
      prev = curr;
      os_setTimedCallback(&sendjob, os_getTime()+sec2osticks(TX_INTERVAL), do_send);
    }

      
}

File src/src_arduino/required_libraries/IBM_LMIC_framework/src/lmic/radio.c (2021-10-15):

/*******************************************************************************
 * Copyright (c) 2014-2015 IBM Corporation.
 * All rights reserved. This program and the accompanying materials
 * are made available under the terms of the Eclipse Public License v1.0
 * which accompanies this distribution, and is available at
 * http://www.eclipse.org/legal/epl-v10.html
 *
 * Contributors:
 *    IBM Zurich Research Lab - initial API, implementation and documentation
 *******************************************************************************/

#include "lmic.h"

// ----------------------------------------
// Registers Mapping
#define RegFifo                                    0x00 // common
#define RegOpMode                                  0x01 // common
#define FSKRegBitrateMsb                           0x02
#define FSKRegBitrateLsb                           0x03
#define FSKRegFdevMsb                              0x04
#define FSKRegFdevLsb                              0x05
#define RegFrfMsb                                  0x06 // common
#define RegFrfMid                                  0x07 // common
#define RegFrfLsb                                  0x08 // common
#define RegPaConfig                                0x09 // common
#define RegPaRamp                                  0x0A // common
#define RegOcp                                     0x0B // common
#define RegLna                                     0x0C // common
#define FSKRegRxConfig                             0x0D
#define LORARegFifoAddrPtr                         0x0D
#define FSKRegRssiConfig                           0x0E
#define LORARegFifoTxBaseAddr                      0x0E
#define FSKRegRssiCollision                        0x0F
#define LORARegFifoRxBaseAddr                      0x0F
#define FSKRegRssiThresh                           0x10
#define LORARegFifoRxCurrentAddr                   0x10
#define FSKRegRssiValue                            0x11
#define LORARegIrqFlagsMask                        0x11
#define FSKRegRxBw                                 0x12
#define LORARegIrqFlags                            0x12
#define FSKRegAfcBw                                0x13
#define LORARegRxNbBytes                           0x13
#define FSKRegOokPeak                              0x14
#define LORARegRxHeaderCntValueMsb                 0x14
#define FSKRegOokFix                               0x15
#define LORARegRxHeaderCntValueLsb                 0x15
#define FSKRegOokAvg                               0x16
#define LORARegRxPacketCntValueMsb                 0x16
#define LORARegRxpacketCntValueLsb                 0x17
#define LORARegModemStat                           0x18
#define LORARegPktSnrValue                         0x19
#define FSKRegAfcFei                               0x1A
#define LORARegPktRssiValue                        0x1A
#define FSKRegAfcMsb                               0x1B
#define LORARegRssiValue                           0x1B
#define FSKRegAfcLsb                               0x1C
#define LORARegHopChannel                          0x1C
#define FSKRegFeiMsb                               0x1D
#define LORARegModemConfig1                        0x1D
#define FSKRegFeiLsb                               0x1E
#define LORARegModemConfig2                        0x1E
#define FSKRegPreambleDetect                       0x1F
#define LORARegSymbTimeoutLsb                      0x1F
#define FSKRegRxTimeout1                           0x20
#define LORARegPreambleMsb                         0x20
#define FSKRegRxTimeout2                           0x21
#define LORARegPreambleLsb                         0x21
#define FSKRegRxTimeout3                           0x22
#define LORARegPayloadLength                       0x22
#define FSKRegRxDelay                              0x23
#define LORARegPayloadMaxLength                    0x23
#define FSKRegOsc                                  0x24
#define LORARegHopPeriod                           0x24
#define FSKRegPreambleMsb                          0x25
#define LORARegFifoRxByteAddr                      0x25
#define LORARegModemConfig3                        0x26
#define FSKRegPreambleLsb                          0x26
#define FSKRegSyncConfig                           0x27
#define LORARegFeiMsb                              0x28
#define FSKRegSyncValue1                           0x28
#define LORAFeiMib                                 0x29
#define FSKRegSyncValue2                           0x29
#define LORARegFeiLsb                              0x2A
#define FSKRegSyncValue3                           0x2A
#define FSKRegSyncValue4                           0x2B
#define LORARegRssiWideband                        0x2C
#define FSKRegSyncValue5                           0x2C
#define FSKRegSyncValue6                           0x2D
#define FSKRegSyncValue7                           0x2E
#define FSKRegSyncValue8                           0x2F
#define FSKRegPacketConfig1                        0x30
#define FSKRegPacketConfig2                        0x31
#define LORARegDetectOptimize                      0x31
#define FSKRegPayloadLength                        0x32
#define FSKRegNodeAdrs                             0x33
#define LORARegInvertIQ                            0x33
#define FSKRegBroadcastAdrs                        0x34
#define FSKRegFifoThresh                           0x35
#define FSKRegSeqConfig1                           0x36
#define FSKRegSeqConfig2                           0x37
#define LORARegDetectionThreshold                  0x37
#define FSKRegTimerResol                           0x38
#define FSKRegTimer1Coef                           0x39
#define LORARegSyncWord                            0x39
#define FSKRegTimer2Coef                           0x3A
#define FSKRegImageCal                             0x3B
#define FSKRegTemp                                 0x3C
#define FSKRegLowBat                               0x3D
#define FSKRegIrqFlags1                            0x3E
#define FSKRegIrqFlags2                            0x3F
#define RegDioMapping1                             0x40 // common
#define RegDioMapping2                             0x41 // common
#define RegVersion                                 0x42 // common
// #define RegAgcRef                                  0x43 // common
// #define RegAgcThresh1                              0x44 // common
// #define RegAgcThresh2                              0x45 // common
// #define RegAgcThresh3                              0x46 // common
// #define RegPllHop                                  0x4B // common
// #define RegTcxo                                    0x58 // common
#define RegPaDac                                   0x5A // common
// #define RegPll                                     0x5C // common
// #define RegPllLowPn                                0x5E // common
// #define RegFormerTemp                              0x6C // common
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

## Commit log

2021-11-03 job submit bugfix
    [lora_apb_config_example.txt]
2021-11-03 pin fix
2021-11-03 introduce new payload format
    currently arduino only
